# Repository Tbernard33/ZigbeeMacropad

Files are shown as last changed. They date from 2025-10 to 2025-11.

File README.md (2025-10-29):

# 🧠 Zigbee Macropad (ESP32-C6)

A compact **16-key Zigbee macropad** powered by the an **ESP32-C6**, designed for integration with **Home Assistant (ZIGBEE2MQTT)**.  
It provides tactile mechanical key input, configurable LED feedback, and a fully 3D-printed case.
It gives 3 sorts of inputs, single click, double clicks and long click to add into any automation to control device remotely.

---

## ⚙️ Hardware

| Component | Description |
|---|---|
| **MCU** | nanoESP32-C6-N8 |
| **Switches** | 16 x Cherry MX Red (linear) |
| **Battery** | 2 x EBL 1.5 V lithium-ion rechargeable AA cell |
| **Buttons** | 6 mm tactile push button (BOOT / Reset) |
| **Power switch** | 13 mm by 8.5 mm on/off slide switch |
| **BOOST Converter** | MT3608 DC-DC Boost converter (3.1v to 3.3v) |
| **Magnets** | 4 x 10 mm × 2 mm neodymium discs |
| **Threaded inserts** | 4 x M2.5 heat-set brass inserts |
| **Screws** | 4 x M2.5 × 5 mm machine screws |
| **Case** | 3D-printed PLA enclosure (about 79g with cap switches and supports) |

---

## 🧩 3D-Printed Parts

Designed and customized in **Tinkercad**, printed with **Centauri Carbon and white PLA**.  
Printed at 0.2 mm layer height, 15–20% infill, no supports required.

### 🔗 Remixed Models
- [16 Keys Macropad](https://www.printables.com/model/140766-16-keys-macropad)  
- [AA Battery Holder for Dupont Jumper](https://www.printables.com/model/380920-aa-battery-holder-for-dupont-jumper)  
- [Simple Cherry MX Keycap](https://www.printables.com/model/118708-simple-cherry-mx-keycap)

---

## 💻 Code

Development began in **Arduino IDE**, later migrated to **VS Code with ESP-IDF v5.3.4** for Zigbee and multitasking support.

### 🧠 Software Stack
- **Framework:** ESP-IDF v5.3.4  
- **Zigbee SDK:** [Espressif ESP-Zigbee-SDK](https://github.com/espressif/esp-zigbee-sdk)  
- **Zigbee Role:** Router / End Device  
- **Endpoint Type:** HA Dimmable Light (only exposes brightness to Home Assistant) WIP

### 🔧 Functionality
- 16 GPIO-connected keys with **single**, **double**, and **long press** detection
- **LED feedback** color for each type of press  
- **LED feedback** brightness controlled via Zigbee “brightness” attribute  
- **BOOT button** triggers Zigbee factory reset and new pairing mode  
- **Blinking red LED** indicates pairing state  
- **Debounce and ISR-driven** button logic for reliability  

---

## 🧰 Build Instructions

### 🪛 1. Print and Prepare the Case
- Print all parts. Only the remix part is present in github, everything else can be found on printables.
- Verify that magnets, switches, and PCB fit snugly before final assembly.
- Insert **M2.5 heat-set inserts** into the designated mounting points using a soldering iron at ~200 °C.

### ⚡ 2. Mount the Components
- **Cherry MX switches**: press-fit into the 16-slot plate, solder to perfboard or PCB or with simple wires.
- **nanoESP32-C6-N8**: simply clip in place with any fixation.
- **6 mm BOOT button**: mount to a small hole on the side (for Zigbee reset). Add some glue from glue gun.
- **Power switch**: connect inline with battery’s.
- **Battery holder**: Press fit battery inside. The EBL battery have a builtin BMS so I glue them in their slot with the micro usb accessible outside.
- **Magnets**: press-fit into the lid and base for a secure snap fit. You can add super glue to make sure they don't move.

### 🔋 3. Wiring Overview
| Connection | Description |
|---|---|
| **GPIO 1–22** | Key matrix or direct inputs for 16 buttons. Connect to one side of every switch and the other to GND. |
| **GPIO 9** | BOOT / Reset button. Connect to one side of the 6mm button and the other to GND. |
| **3.3 V & GND** | Power rails for ESP32-C6 and key pull-ups. |
| **Battery pack** | 3 x 1.5 V Li-ion cell inline. Minus to GND and Plus to 5V (reach 4.5V with no cutout and goes to 0 when empty). |
| **On/Off switch** | Inline with battery lead. |

> 💡 Use internal pull-ups on all button pins; connect switches to **GND**.

### 🔧 4. Flash the Firmware
1. Install **ESP-IDF v5.3.4** (or newer).  
2. Clone or copy the project to your workspace.  
3. Build and flash:
   ```bash
   idf.py set-target esp32c6
   idf.py build
   idf.py flash monitor
The device will start blinking red to indicate Zigbee pairing mode.

## 🔗 Pair with Home Assistant

In Home Assistant, open Settings → Devices & Services → Zigbee2MQTT → Permit join.
Power on the macropad — it will appear as a Dimmable Light.
Adjust the brightness slider to set LED feedback intensity.
Test button clicks (single, double, long) — LED flashes will reflect the configured brightness.

## ✨ Features Summary

🔘 16 mechanical switches with multiple click detection
💡 LED feedback brightness linked to Zigbee brightness setting
🔄 BOOT button triggers factory reset and re-pairing
🔴 Blinking red LED during pairing
🧱 Modular, 3D-printed enclosure with magnets and inserts
🪫 Battery powered with on/off switch

## 🧾 License

This project is released under the MIT License.
Remixed 3D models remain under their respective creator licenses (see linked Printables pages).

## 📸 Gallery

//TODO Add pictures

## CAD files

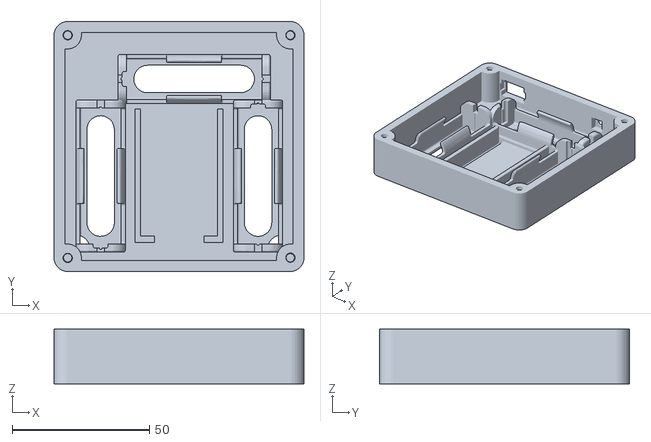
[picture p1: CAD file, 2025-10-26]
Models/ZigbeeMacropadBottomCoverV6.stl
91.2 x 91.2 x 20.0

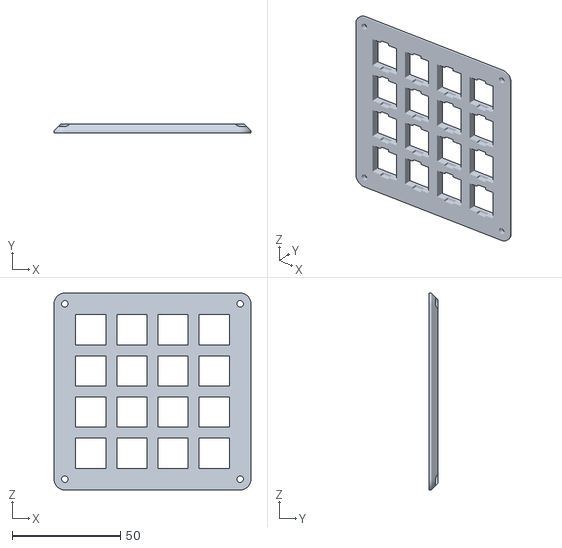
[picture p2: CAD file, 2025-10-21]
Models/OriginalTopCover.stl
91.2 x 4.00 x 91.2

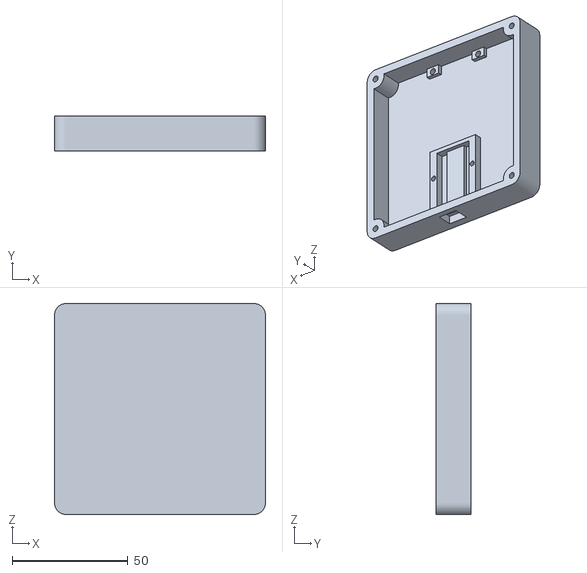
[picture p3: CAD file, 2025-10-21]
Models/OriginalBottomCover.stl
91.2 x 15.0 x 91.2

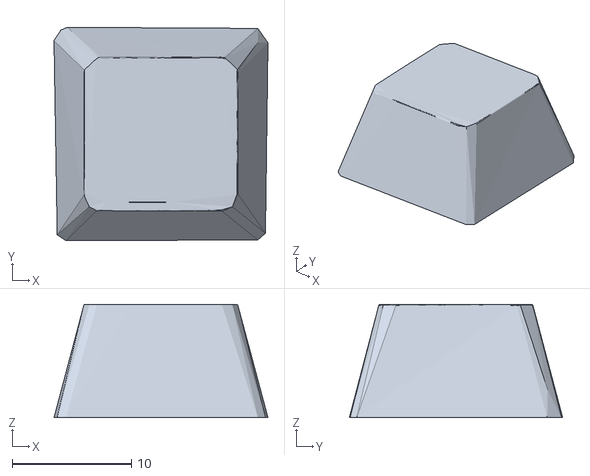
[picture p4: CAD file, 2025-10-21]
Models/Simple-CherryMX-Keycap.stl
18.0 x 17.9 x 9.50

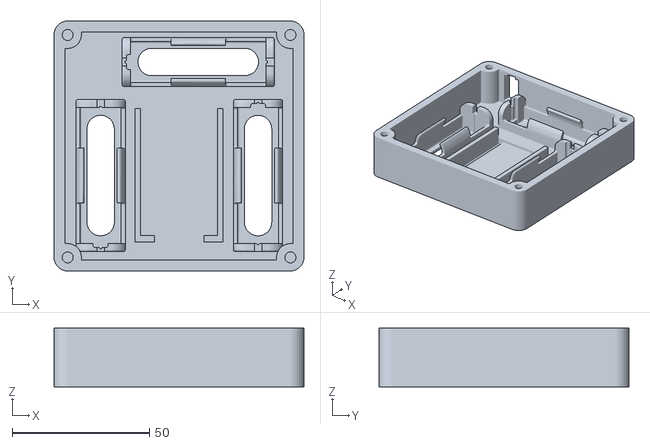
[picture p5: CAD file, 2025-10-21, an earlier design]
Models/ZigbeeMacropadBottomCoverV3.stl
91.2 x 91.2 x 21.5

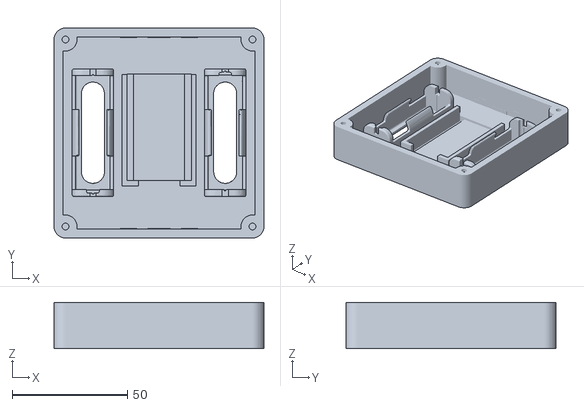
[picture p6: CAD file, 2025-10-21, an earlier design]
Models/ZigbeeMacropadBottomCoverV1.stl
91.2 x 91.2 x 20.0

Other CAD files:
Models/ZigbeeMacropadBottomCoverV4.stl
Models/ZigbeeMacropadBottomCoverV5.stl

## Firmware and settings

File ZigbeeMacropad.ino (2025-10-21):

// nanoESP32-C6-N8 — 16-button Zigbee remote with RGB LED and pairing support
#ifndef ZIGBEE_MODE_ED 
#error "Zigbee end device mode is not selected in Tools->Zigbee mode" 
#endif

#include <Arduino.h>
#include <Adafruit_NeoPixel.h>
#include <Zigbee.h>

// ----------------------- Hardware configuration -----------------------
#define BUTTON_COUNT 16
const uint8_t buttonPins[BUTTON_COUNT] = {
  1, 2, 3, 4, 5, 6, 7, 10,
  11, 12, 13, 18, 19, 20, 21, 22
};

#define BOOT_BUTTON 9
#define NEOPIXEL_PIN 8
#define NUM_PIXELS 1

// ----------------------- Timing and thresholds ------------------------
constexpr unsigned long DEBOUNCE_MS = 30;
constexpr unsigned long DOUBLE_MS = 400;
constexpr unsigned long LONG_MS = 1000;
constexpr unsigned long EVENT_FLASH_MS = 150;

// ----------------------- LED and colors -------------------------------
Adafruit_NeoPixel rgbLed(NUM_PIXELS, NEOPIXEL_PIN, NEO_GRB + NEO_KHZ800);

struct RGB { uint8_t r, g, b; };
const RGB COLOR_OFF    = {0, 0, 0};
const RGB COLOR_GREEN  = {0, 255, 0};
const RGB COLOR_BLUE   = {0, 0, 255};
const RGB COLOR_YELLOW = {255, 255, 0};
const RGB COLOR_RED    = {255, 0, 0};

volatile uint8_t ledBrightness = 50;

// Helper: set the NeoPixel color scaled by brightness (0..100)
void setNeoPixelColor(const RGB &c, uint8_t brightnessPercent = 100) {
  uint16_t scale = (uint16_t)brightnessPercent * 255 / 100;
  uint8_t r = (uint8_t)(((uint16_t)c.r * scale) / 255);
  uint8_t g = (uint8_t)(((uint16_t)c.g * scale) / 255);
  uint8_t b = (uint8_t)(((uint16_t)c.b * scale) / 255);
  rgbLed.setPixelColor(0, rgbLed.Color(r, g, b));
  rgbLed.show();
}

void flashNeoPixel(const RGB &c, uint16_t duration_ms = EVENT_FLASH_MS) {
  setNeoPixelColor(c, ledBrightness);
  delay(duration_ms);
  setNeoPixelColor(COLOR_OFF);
}

// ----------------------- Button logic ---------------------------------
bool lastRawState[BUTTON_COUNT];
bool stableState[BUTTON_COUNT];
unsigned long lastStableTime[BUTTON_COUNT];
unsigned long pressStartTime[BUTTON_COUNT];
unsigned long lastReleaseTime[BUTTON_COUNT];
bool longAlreadyTriggered[BUTTON_COUNT];

void handleButtons(void (*onAction)(uint8_t, const char *)) {
  unsigned long now = millis();
  for (uint8_t i = 0; i < BUTTON_COUNT; ++i) {
    bool raw = (digitalRead(buttonPins[i]) == LOW);
    if (raw != lastRawState[i]) {
      lastRawState[i] = raw;
      lastStableTime[i] = now;
    }

    if ((now - lastStableTime[i]) >= DEBOUNCE_MS) {
      if (raw != stableState[i]) {
        stableState[i] = raw;
        if (stableState[i]) {
          pressStartTime[i] = now;
          longAlreadyTriggered[i] = false;
        } else {
          unsigned long pressDur = now - pressStartTime[i];
          if (!longAlreadyTriggered[i]) {
            if (lastReleaseTime[i] && (now - lastReleaseTime[i]) <= DOUBLE_MS) {
              onAction(i, "double");
              lastReleaseTime[i] = 0;
            } else {
              lastReleaseTime[i] = now;
            }
          } else {
            lastReleaseTime[i] = 0;
          }
        }
      }
    }

    if (stableState[i] && !longAlreadyTriggered[i] &&
        (now - pressStartTime[i]) >= LONG_MS) {
      longAlreadyTriggered[i] = true;
      onAction(i, "long");
      lastReleaseTime[i] = 0;
    }

    if (lastReleaseTime[i] && ((now - lastReleaseTime[i]) > DOUBLE_MS)) {
      onAction(i, "single");
      lastReleaseTime[i] = 0;
    }
  }
}

// ----------------------- Zigbee endpoint ------------------------------
#define ZIGBEE_ENDPOINT 10
ZigbeeColorDimmableLight zbLight(ZIGBEE_ENDPOINT);

void zigbeeLightChanged(bool state, uint8_t r, uint8_t g, uint8_t b, uint8_t level) {
  ledBrightness = constrain(level, 0, 100);
  if (state) setNeoPixelColor({r, g, b}, ledBrightness);
  else setNeoPixelColor(COLOR_OFF);
}

void emitZigbeeAction(uint8_t index, uint8_t actionCode, const RGB &color) {
  uint8_t level = (index) * 6 + actionCode;
  zbLight.setLight(true, level, color.r, color.g, color.b);
  delay(60);
  zbLight.setLight(false, 0, 0, 0, 0);
}

void onButtonAction(uint8_t index, const char *action) {
  Serial.printf("Button %u -> %s\n", index + 1, action);

  RGB color = COLOR_OFF;
  uint8_t actionCode = 0;
  if (strcmp(action, "single") == 0) { color = COLOR_GREEN; actionCode = 1; }
  else if (strcmp(action, "double") == 0) { color = COLOR_BLUE; actionCode = 2; }
  else if (strcmp(action, "long") == 0) { color = COLOR_YELLOW; actionCode = 3; }

  flashNeoPixel(color);
  emitZigbeeAction(index, actionCode, color);
}

// ----------------------- Boot button pairing --------------------------
bool pairingActive = false;

void startPairing() {
  pairingActive = true;
  Serial.println("[ZB] Factory reset + Zigbee pairing...");
  Zigbee.factoryReset();   // starts join mode
}

void updatePairingLED() {
  static unsigned long lastBlink = 0;
  static bool on = false;

  if (!Zigbee.connected()) {
    unsigned long now = millis();
    if (now - lastBlink > 300) {
      lastBlink = now;
      on = !on;
      if (on) setNeoPixelColor(COLOR_RED, ledBrightness);
      else setNeoPixelColor(COLOR_OFF);
    }
  } else if (on) {
    on = false;
    setNeoPixelColor(COLOR_OFF);
  }
}

// ----------------------- Setup & loop ---------------------------------
void setup() {
  Serial.begin(115200);
  rgbLed.begin();
  setNeoPixelColor(COLOR_OFF);

  for (uint8_t i = 0; i < BUTTON_COUNT; ++i) {
    pinMode(buttonPins[i], INPUT_PULLUP);
    stableState[i] = false;
    lastRawState[i] = digitalRead(buttonPins[i]) == LOW;
    lastStableTime[i] = millis();
  }
  pinMode(BOOT_BUTTON, INPUT_PULLUP);

  zbLight.setManufacturerAndModel("Custom", "ZB16BtnRemote");
  zbLight.onLightChange(zigbeeLightChanged);
  Zigbee.addEndpoint(&zbLight);

  if (!Zigbee.begin()) {
    Serial.println("Zigbee failed to start!");
    delay(2000);
    ESP.restart();
  }

  Serial.println("[ZB] Starting...");
  while (!Zigbee.connected()) {
    Serial.print(".");
    delay(200);
  }
  Serial.println("\n[ZB] Connected.");
}

void loop() {
  handleButtons(onButtonAction);

  if (digitalRead(BOOT_BUTTON) == LOW && !pairingActive) {
    delay(100);
    if (digitalRead(BOOT_BUTTON) == LOW) {
      startPairing();
    }
  }

  updatePairingLED();
}

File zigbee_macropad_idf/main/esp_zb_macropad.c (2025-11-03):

/*
 * Zigbee HA_color_dimmable_light Example (ESP32-C6)
 * -------------------------------------------------
 * Simplified for MACROPAD:
 *  - Only Zigbee Level Control / Current Level is honored.
 *  - That brightness is used for the short LED feedback when a key is pressed.
 *  - Color & On/Off writes are ignored.
 *  - Pairing still blinks RED while not joined.
 */

#include <stdio.h>
#include <string.h>
#include "esp_zb_macropad.h"
#include "esp_check.h"
#include "esp_log.h"
#include "nvs_flash.h"
#include "driver/gpio.h"
#include "freertos/FreeRTOS.h"
#include "freertos/task.h"
#include "freertos/queue.h"
#include "ha/esp_zigbee_ha_standard.h"
#include "esp_timer.h"

#if !defined CONFIG_ZB_ZCZR
#error Define ZB_ZCZR in idf.py menuconfig to compile light (Router) source code.
#endif

#define TAG                 "MACROPAD"

/* --- PINS --------------------------------------------------------------- */
#define BTN_COUNT 16
static const gpio_num_t BTN_PINS[BTN_COUNT] = {
    GPIO_NUM_1,  GPIO_NUM_2,  GPIO_NUM_3,  GPIO_NUM_4,
    GPIO_NUM_5,  GPIO_NUM_6,  GPIO_NUM_7,  GPIO_NUM_10,
    GPIO_NUM_11, GPIO_NUM_12, GPIO_NUM_13, GPIO_NUM_18,
    GPIO_NUM_19, GPIO_NUM_20, GPIO_NUM_21, GPIO_NUM_22
};
#define BOOT_BUTTON_GPIO     GPIO_NUM_9

/* --- Timing (ms) for local keypad -------------------------------------- */
#define BTN_POLL_INTERVAL_MS   10
#define DEBOUNCE_MS        30
#define DOUBLE_CLICK_MS   400
#define LONG_PRESS_MS    1000
#define CUSTOM_CLUSTER_ID        0xFC00    // arbitrary manufacturer-specific range
#define ATTR_BRIGHTNESS_ID       0x0001
#define CONFIG_ENDPOINT     10

static uint32_t zb_brightness = 100; // default brightness (0–255)

/* --- Button state machine ----------------------------------------------- */
typedef struct {
    bool raw;
    bool stable;
    bool prev_stable;
    uint64_t last_change_us;
    uint64_t press_start_us;
    uint64_t last_release_us;
    bool long_fired;
} btn_state_t;

typedef struct {
    uint8_t idx;       // which button (0–15)
    uint64_t timestamp_us;
    bool level;        // 0 = pressed, 1 = released
} btn_evt_t;

static QueueHandle_t s_boot_evt_q = NULL;

static btn_state_t g_btn[BTN_COUNT];

/* --- Zigbee + LED state ------------------------------------------------- */
static bool g_is_joined     = false;
static bool g_blinking      = false;
static bool g_driver_ready  = false;
static bool g_blink_on      = false;
static bool g_zb_ready      = false;

/* Brightness (0..254 from Zigbee Level Control); used for key feedback */
static uint8_t g_feedback_level = 80;

/* --- Helpers ------------------------------------------------------------ */
static inline uint64_t now_us(void) { return esp_timer_get_time(); }
static inline uint32_t us_to_ms(uint64_t us) { return (uint32_t)(us / 1000ULL); }

typedef enum { ACT_NONE, ACT_SINGLE, ACT_DOUBLE, ACT_LONG } action_t;

/* --- Forward declarations  ------------------------------------------------------ */
static const char* action_str(action_t a);
static void flash_action(action_t a, uint8_t brightness);
static void start_network_steering(uint8_t param);
static void zb_blink_step(void);
static void zb_reset_and_steer_cb(void);

/* ======================================================================= */
/*                          BLINKER (ZB CONTEXT)                           */
/* ======================================================================= */
static void zb_blink_step(void)
{
    if (!g_driver_ready) {
        esp_zb_scheduler_alarm_cancel((esp_zb_callback_t)zb_blink_step, 0);
        esp_zb_scheduler_alarm((esp_zb_callback_t)zb_blink_step, 0, 500);
        return;
    }

    if (!g_blinking) {
        if (g_blink_on) {                  // ensure off
            light_driver_set_level(0);
            light_driver_set_power(false);
            g_blink_on = false;
        }
        esp_zb_scheduler_alarm_cancel((esp_zb_callback_t)zb_blink_step, 0);
        return;
    }

    g_blink_on = !g_blink_on;
    if (g_blink_on) {
        light_driver_set_color_xy(0xA3D6, 0x547B);  // red
        //green : Color X: 0x4ccd  Color Y: 0x9999
        //blue : Color X: 0x2666  Color Y: 0x0f5c
        //yellow : Color X: 0x6b58  Color Y: 0x8157
        light_driver_set_power(true);
        light_driver_set_level(100);   // adjust if you want dimmer pairing
    } else {
        light_driver_set_level(0);
    }

    /* Reschedule single instance */
    esp_zb_scheduler_alarm_cancel((esp_zb_callback_t)zb_blink_step, 0);
    esp_zb_scheduler_alarm((esp_zb_callback_t)zb_blink_step, 0, 300);
}

static void zb_stop_pairing_blink(void)
{
    g_blinking = false;
    if (g_blink_on) {
        light_driver_set_level(0);
        light_driver_set_power(false);
        g_blink_on = false;
    }
    esp_zb_scheduler_alarm_cancel((esp_zb_callback_t)zb_blink_step, 0);
}

/* ======================================================================= */
/*                   FACTORY RESET + COMMISSION (ZB CTX)                   */
/* ======================================================================= */
static void start_network_steering(uint8_t param)
{
    (void)param;
    esp_zb_bdb_start_top_level_commissioning(ESP_ZB_BDB_MODE_NETWORK_STEERING);
}

static void zb_reset_and_steer_cb(void)
{
    ESP_LOGW(TAG, "Factory reset: clearing Zigbee NVS and restarting commissioning...");
    g_is_joined = false;
    g_blinking  = true;

    esp_zb_factory_reset();

    /* Start fresh blink loop (single instance) */
    esp_zb_scheduler_alarm_cancel((esp_zb_callback_t)zb_blink_step, 0);
    esp_zb_scheduler_alarm((esp_zb_callback_t)zb_blink_step, 0, 0);

    /* Start network steering shortly after */
    esp_zb_scheduler_alarm(start_network_steering, 0, 1500);
}

/* ======================================================================= */
/*                      BOOT BUTTON (ISR + QUEUE)                          */
/* ======================================================================= */
static void IRAM_ATTR boot_button_isr(void *arg) {
    uint32_t dummy = 1;
    xQueueSendFromISR(s_boot_evt_q, &dummy, NULL);
}

static void boot_button_task(void *arg) {
    uint32_t dummy;
    while (1) {
        if (xQueueReceive(s_boot_evt_q, &dummy, portMAX_DELAY)) {
            if (g_zb_ready) {
                esp_zb_scheduler_alarm((esp_zb_callback_t)zb_reset_and_steer_cb, 0, 0);
            } else {
                ESP_LOGW(TAG, "Zigbee not ready; ignoring button press");
            }
        }
    }
}

/* ======================================================================= */
/*                     LOCAL FEEDBACK (color fixed)                         */
/* ======================================================================= */
static const char* action_str(action_t a) {
    return (a==ACT_SINGLE) ? "single" : (a==ACT_DOUBLE) ? "double" : "long";
}
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

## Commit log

2025-10-21 ZigbeeMarcoPad WIP
    First commit with WIP version working with 16 buttons and in zigbee.
2025-10-21 Rework macropad model to add higher walls to fil top cover and switches and a third battery
    Third battery is needed to reach 4.5-4.7V. The previous setup with 3-3.15V wasn't sufficiant to power the board.
    [ZigbeeMacropadBottomCoverV1.stl, ZigbeeMacropadBottomCoverV2.stl]
2025-10-21 Rework marcopad cover to allow for more space for cables and a on/off switch.
    [ZigbeeMacropadBottomCoverV3.stl]
2025-10-21 Fix led not blinking on click.
    [ZigbeeMacropad.ino]
2025-10-21 Improve js for custom device + Improve behavior and try fix led blinking.
    [ZigbeeMacropad.ino]
2025-10-22 Full basic idf project with working pins and light changes on gpio button press without any zigbee logic.
    [partitions.csv]
2025-10-23 Rebuild ESP-IDF project with proper settings for basic zigbee_dimmable_light_example.
    [partitions.csv]
2025-10-23 Rework pairing system to add blinking.
    [esp_zb_light.c]
2025-10-24 Fix red blinking color.
    [esp_zb_light.c]
2025-10-26 Models improvement.
    [ZigbeeMacropadBottomCoverV4.stl, ZigbeeMacropadBottomCoverV5.stl, ZigbeeMacropadBottomCoverV6.stl]
2025-10-26 WIP button behavior addition to zigbee.
2025-10-27 Global clean code. Fix button clicking detection.
    [esp_zb_light.c]
2025-10-27 Restore button polling instead of isr for macropad buttons.
2025-10-29 Rename main classes + improve end of pairing with led + try custom attributes (failed)
    [esp_zb_macropad.c]
